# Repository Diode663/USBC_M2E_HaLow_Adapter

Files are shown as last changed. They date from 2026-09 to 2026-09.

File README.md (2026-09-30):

# USB-C to M.2 Key-E HaLow adapter

USB 2.0 over a USB-C receptacle to an M.2 2230 Key-E socket, for the Gateworks
GW16170 (Morse Micro MM8108-M20) Wi-Fi HaLow card. 56.5 x 40.5 mm, 2-layer
(JLCPCB JLC0216A), single-sided assembly.

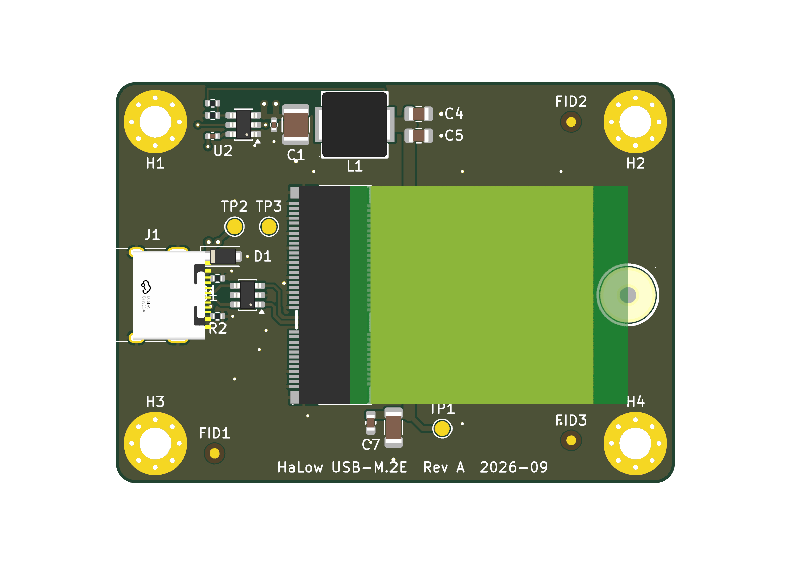
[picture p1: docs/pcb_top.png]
Top view with the card envelope


> **Status: Rev A is built and works as designed** (boards assembled by JLCPCB, confirmed by the
> author on 2026-09-29). The project is closed; no Rev B is planned.
> Test procedure: [`docs/Test_Procedure.md`](docs/Test_Procedure.md). Pre-fabrication review:
> [`docs/Design_Review_2026-09-20.md`](docs/Design_Review_2026-09-20.md).

| Block | Parts |
|---|---|
| USB-C input | J1 HRO TYPE-C-31-M-12, R1/R2 5.1k CC pull-downs, U1 USBLC6-2SC6, D1 SMF5.0A |
| 3.3 V / 3 A buck | U2 TPS563201, L1 2.2 uH, C1/C2 in, C4/C5 out, R3/R4 33.2k/10k = 3.32 V |
| M.2 socket | J2 MLD-NGFF-E-4.2H, C6 100 uF, C7 10 uF, C8/C9 100 nF |
| Mechanical | H1-H4 M3, H5 SMTSOM225BTR M2 x 2.5 mm SMT nut for the card |

Only USB D+/D- (M.2 pins 3 and 5), 3.3 V and ground go to the card. W_DISABLE1# (the card's
reset) and W_DISABLE2# (wake) are left open on purpose: the card has its own pull-ups, and its
reset pin uses a power-on RC that an external pull-up would defeat.

## Bill of materials

Full BOM with notes and the parts you supply yourself: **[`BOM.md`](BOM.md)**.
The CSV that went to JLCPCB: [`fab/USBC_M2E_HaLow_Adapter_bom.csv`](fab/USBC_M2E_HaLow_Adapter_bom.csv).

| Ref | Qty | Value | Part number | LCSC |
|---|---|---|---|---|
| U2 | 1 | 3 A buck regulator | TPS563201DDCR | C116592 |
| U1 | 1 | USB ESD array | USBLC6-2SC6 | C7519 |
| D1 | 1 | 5 V TVS | SMF5.0A | C19077497 |
| L1 | 1 | 2.2 µH | CYA0630-2.2UH | C5189746 |
| J1 | 1 | USB-C receptacle | TYPE-C-31-M-12 | C165948 |
| J2 | 1 | M.2 Key-E socket, 4.2 mm | MLD-NGFF-E-4.2H | C52766479 |
| H5 | 1 | M2 x 2.5 mm SMT nut | SMTSOM225BTR | C5301773 |
| C1 | 1 | 10 µF 25 V, 1210 | GRM32DR71E106KA12L | C77100 |
| C6 | 1 | 100 µF 6.3 V, 1206 | CL31A107MQHNNNE | C15008 |
| C4, C5 | 2 | 22 µF 25 V, 0805 | CL21A226MAQNNNE | C45783 |
| C7 | 1 | 10 µF 10 V, 0603 | CL10A106KP8NNNC | C19702 |
| C2, C3, C8, C9 | 4 | 100 nF 16 V, 0402 | CL05B104KO5NNNC | C1525 |
| R1, R2 | 2 | 5.1 kΩ 1 %, 0402 | 0402WGF5101TCE | C25905 |
| R3 | 1 | 33.2 kΩ 1 %, 0402 | FRC0402F3322TS | C2930001 |
| R4 | 1 | 10 kΩ 1 %, 0402 | 0402WGF1002TCE | C25744 |

You also need the GW16170 card, an M2 x 3–4 mm screw, an MMCX antenna or pigtail, and a short
3 A USB-C cable on a port that can supply about 0.9 A.

## How it was made

Everything is generated from Python. Edit the scripts, not the KiCad files. Run with KiCad's Python:

    "C:\Program Files\KiCad\10.0\bin\python.exe" generate_schematic.py --force
    "C:\Program Files\KiCad\10.0\bin\python.exe" autoplace.py . --floorplan
    "C:\Program Files\KiCad\10.0\bin\python.exe" autoplace.py . --place --force
    "C:\Program Files\KiCad\10.0\bin\python.exe" setup_fab.py
    "C:\Program Files\KiCad\10.0\bin\python.exe" route_board.py
    "C:\Program Files\KiCad\10.0\bin\python.exe" drc_report.py
    "C:\Program Files\KiCad\10.0\bin\python.exe" check_m2_clearance.py
    "C:\Program Files\KiCad\10.0\bin\python.exe" build_package.py

`--place` resets every unlocked footprint. Designators moved by hand in KiCad are detected and
kept (`.pcbgen-refs.json`). `route_board.py` redraws every track, via and pour each time it runs.
`build_package.py` writes `fab/` and refuses to run unless DRC is clean.

Mechanical facts, from the MLD-NGFF-E-4.2H drawing:
- the card extends from the even-pin / locating-peg side of the socket;
- the card stop is 1.75 mm behind the pegs, so the 2230 notch is 29.75 mm from the socket centre;
- the card's underside is 2.52 mm above the board; parts under it must be 0.90 mm or lower.

JLCPCB: `setup_fab.py` writes their 2-layer rules into the project and into
`USBC_M2E_HaLow_Adapter.kicad_dru`, with the source pages and date in its docstring. The USB pair
is 0.3345 / 0.1524 mm with ground pour 0.2032 mm either side, from JLCPCB's own calculator for
stackup JLC0216A. JLCPCB does not test impedance on 2-layer boards. `jlc_rotations.json` holds
the placement-file corrections with the evidence for each.

## Repository contents
- `USBC_M2E_HaLow_Adapter.kicad_*`: the KiCad 10 project, schematic, routed board and custom design rules.
- `fab/`: the package sent to JLCPCB for Rev A (gerbers zip, BOM, placement file, order notes).
- `docs/`: schematic PDF, renders, copper images, the pre-fabrication design review and the board test procedure.
- `library/`: project symbols, footprints and 3D models.
- `*.py`: the generators. `schlib.py`, `subcircuits.py`, `pcblib.py`, `autoplace.py`, `recipes.py` and `jlc_cpl.py` are copies of the libraries the project was generated with.
- Vendor datasheets are not included.

## Licence

Copyright Diode663 2026.

**Hardware** (the KiCad project, schematic, board, the project's own symbols and footprints,
fabrication outputs and documentation): this source describes Open Hardware and is licensed under
the CERN-OHL-P v2. You may redistribute and modify this source and make products using it under
the terms of the CERN-OHL-P v2 (<https://ohwr.org/cern_ohl_p_v2.txt>), a copy of which is in
[`LICENSE`](LICENSE). This source is distributed WITHOUT ANY EXPRESS OR IMPLIED WARRANTY,
INCLUDING OF MERCHANTABILITY, SATISFACTORY QUALITY AND FITNESS FOR A PARTICULAR PURPOSE. Please
see the CERN-OHL-P v2 for applicable conditions.
Source location: <https://github.com/Diode663/USBC_M2E_HaLow_Adapter>

**Software** (every `*.py` file): MIT, see [`LICENSE-MIT`](LICENSE-MIT).

**Not covered by either licence** — third-party material, included for convenience and owned by
its respective rights holders:
- footprints and 3D models obtained from LCSC / EasyEDA with `easyeda2kicad`:
  `library/HaLowAdapter.pretty/CONN-SMD_MLD-NGFF-E-4.2H.kicad_mod`, `IND-SMD_L7.2-W6.6_GPSR07X0.kicad_mod`,
  `SMTSO_M2_H2.5_SMTSOM225BTR.kicad_mod`, and in `library/HaLowAdapter.3dshapes/` the
  `USB-C_SMD-TYPE-C-31-M-12_1`, `IND-SMD_L7.2-W6.6-H3.0_GPSR07X0` and `SMD_BD5.6-D3.6` models;
- `USB_C_Receptacle_HRO_TYPE-C-31-M-12.kicad_mod` and the M.2 socket symbol, which are modified
  copies from the KiCad libraries (CC-BY-SA 4.0 with the KiCad library exception).

Gateworks, Morse Micro, JLCPCB and the part manufacturers are not affiliated with this project.

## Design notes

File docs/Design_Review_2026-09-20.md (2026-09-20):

# USB-C to M.2 Key-E HaLow Adapter — Design Review

**Project:** USBC_M2E_HaLow_Adapter (KiCad 10, single sheet, 2-layer PCB 56.5 x 40.5 mm, JLCPCB turnkey)
**Date:** 2026-09-20
**Analyzers run:** analyze_schematic.py, analyze_pcb.py `--full --proximity`, cross_analysis.py, analyze_emc.py, analyze_thermal.py, lifecycle_audit.py (LCSC only), KiCad DRC with schematic parity, project `check_m2_clearance.py`, deep review pass with the citation gate.
**Run folder:** `analysis/2026-09-20_1330/`, deep review in `analysis/deep_review.json`, numbers from `analysis/helpers/buck_usb_checks.py`.

## Overview
USB 2.0 over a USB-C receptacle (J1) to an M.2 2230 Key-E socket (J2) for a Gateworks GW16170 HaLow card. A TPS563201 buck (U2) makes 3.3 V from VBUS. ESD array U1 on D+/D-, TVS D1 on VBUS, 5.1k sink resistors on CC1/CC2. 24 parts, 10 routed nets, everything on the top side, solid ground pour on both layers.

No prior review or analyzer runs existed, so there is no delta section.

## Critical Findings

| Severity | Issue | Section |
|---|---|---|
| WARNING | +3V3 output capacitance (154 uF nominal, ~87 uF effective) is above TI's 20-68 uF range with L1 at its 4.7 uH maximum. LC pole 5.9-7.9 kHz vs TI's 8.9-24 kHz envelope. | Power |
| WARNING | A ground stitching via sits inside J2's hold-down tab pad 76. Solder will wick down it and weaken a mechanical joint. | Layout |
| WARNING | The ground via under U1 is 0.5/0.3 mm: 0.10 mm annular ring, below IPC Class 2 (0.125 mm). JLCPCB can build it; a 0.6/0.3 via fits. | Layout |

No CRITICAL issues. Nothing found that would stop the board from working.

## Component Summary
Capacitors 9, resistors 4, inductor 1, TVS 1, ICs 2, connectors 2, mounting parts 5. 63 nets (53 are single-pin no-connect nets on J2), 3 rails. MPN coverage 100 % of BOM parts. Two BOM lines have no manufacturer recorded: D1 (C19077497) and H5 (C5301773).

## Power Tree
```
USB-C VBUS 5 V --D1 SMF5.0A clamp-- C1 10uF + C2 100nF
   |
   U2 TPS563201 buck, 580 kHz, EN tied to VIN
   |   R3 33.2k / R4 10k -> 0.768 x 4.32 = 3.318 V   (Vref from datasheet)
   |   L1 4.7 uH, C4 + C5 22 uF at the inductor
   +3V3 --> J2 pins 2/4/72/74, C6 100 uF + C7 10 uF + C8/C9 100 nF at the socket
```
Load: GW16170, about 1.2 A at 3.3 V in transmit bursts (estimate; Gateworks publishes no figure), about 0.9 A from VBUS.

## Analyzer Verification (raw file and datasheet)
- Component count: 24 in schematic, 24 footprints on the board. DRC schematic parity 0. **Raw-file verified.**
- U2 pad nets 1 GND, 2 SW, 3 VBUS, 4 FB, 5 VBUS, 6 VBST match TI's pin table (p.3). **Datasheet-verified.**
- U1 pad nets 1/6 D-, 3/4 D+, 2 GND, 5 open match ST Figure 1. **Datasheet-verified.**
- J2 pad numbering, odd/even row positions, locating pegs and card direction match the MLD drawing; USB on pins 3/5 and 3.3 V on 2/4/72/74 match Gateworks' wiki. **Datasheet-verified.**
- D1 cathode (pad 1) on VBUS. **Raw-file verified**; no datasheet for this exact LCSC part.
- J1: KiCad's stock footprint and symbol for this exact MPN, LCSC C165948 as ordered before. **Library-consistent, not re-derived from the HRO datasheet.**
- Regulator Vout: analyzer 3.283 V (heuristic Vref), hand calculation with TI's 0.768 V: 3.318 V. Use 3.32 V.

## Deep Review
Seven findings passed the citation gate (all marked partial because no structured datasheet extractions exist; quotes are from the PDFs). One was quarantined for lack of a datasheet (D1) and is reported below as inference only.

## Signal Analysis — USB 2.0
- Coupled section uses JLCPCB's calculated geometry (0.3345 / 0.1524 mm, ground 0.2032 mm either side) over unbroken bottom ground. JLCPCB does not test impedance on 2-layer boards.
- From J1 through U1 (about 9 mm) D+ and D- run uncoupled, 1.9 mm apart at U1, because the part is flow-through. That section is well above 90 ohm differential. At 9 mm (about 60 ps) against a 500 ps USB 2.0 edge this is acceptable. **Inference-only.**
- Skew about 3 mm, 20 ps, against a 100 ps budget. Each line has one 1.3 mm bottom strap plus two vias as a side branch for the flip pads, not in the main path.
- No series resistors or common-mode choke. Fine for a bus-powered adapter; a choke is the usual fix if radiated emissions from the cable ever matter.

## Power Analysis
- **Output capacitance vs TI Table 2 (WARNING).** TI: "use the values recommended in Table 2": 3.3 V, L 2.2 typ / 4.7 max uH, Cout 20 to 68 uF. The socket's 100 uF sits on the same node through 11 mOhm of trace, so it counts. Effective capacitance uses typical X5R bias curves, not the capacitor datasheets. **Datasheet-verified limit, inference on the effective value.** Fix: L1 to 2.2 uH (same CYA0630 footprint; pole moves to 8.6-11.5 kHz, ripple 0.87 A pk-pk, peak 1.64 A, still far below the 3.3 A valley limit) and optionally C6 to 47 uF.
- **VBUS headroom (INFO).** TI's 75 % duty limit means VIN of at least 4.43 V for 3.3 V out; UVLO wake-up is 4.3 V max. Only 10 uF is allowed on VBUS. A long or thin cable can sag below that during transmit. Measure VBUS at C1 on the first board.
- C1 + C2 = 10.1 uF nominal on VBUS, at the USB limit of 10 uF; effective value under 5 V bias is lower. Acceptable.
- Current paths: VBUS trunk 0.8 mm bottom, +3V3 1.2 mm top, SW 1.2 mm bottom with two vias at each end. One 0.8/0.4 via carries all VBUS current at D1 (0.9 A): within rating, a second via is cheap.
- M.2 3.3 V pins: four at 0.5 A each, 2 A capacity for a 1.2 A load.

## PCB Layout
- DRC: 0 errors, 0 unconnected, parity 0. 51 silkscreen warnings, 49 of them inside stock KiCad footprints (silk 0.10-0.13 mm from their own pads; JLCPCB clips silk at pads).
- M.2 mechanical check: all clear. L1 2.90 mm from the socket housing, 0402s under the card 0.50 mm tall against a 0.90 mm limit, standoff on the notch at 2.50 mm.
- **Via in J2 pad 76 (WARNING):** stitching via at (19.4, 32.4) lands in the hold-down tab. Move it 1 mm south.
- **Under-U1 via ring (WARNING):** change to 0.6/0.3; clearance to U1's pads becomes 0.18 mm against a 0.15 mm rule.
- Buck follows TI Figure 36 with one known deviation (output caps return through pour and plane, not a shared top island). Solid pour connections on all buck ground pads.
- Tombstoning: analyzer rates six 0402s "medium". C2's ground pad is solid into the pour by choice (input loop); the rest have thermal spokes. Accepted.

## Thermal
analyze_thermal.py produced no assessments (no dissipation data in the schematic). Hand estimate: 0.38 W in U2 at 1.2 A, 92.6 C/W, about 35 C rise. Efficiency is assumed at 90 %, not read from TI's curves. No concern. The radio card's own heat is outside this board.

## EMC / Cross-Domain
- SW-001 harmonics of 580 kHz in the 30-88 MHz band: generic to any buck. SW is 24 mm of copper, 18 mm of it on the bottom under the buck. Inductor is shielded (metal composite).
- The HaLow radio listens at 902-928 MHz, 25 mm from the buck. Harmonic energy that high is small, but the receiver is sensitive. **Inference-only:** check receive sensitivity with the buck loaded on the first board.

## Component Lifecycle
LCSC returns no lifecycle status, so all 14 MPNs read "unknown". No distributor API keys are configured. **Not verified.** TPS563201, USBLC6-2SC6 and the Samsung/Murata capacitors are mainstream active parts to my knowledge.

## Manufacturing / DFM / Testability
- JLCPCB Economic PCBA limits met (2-layer, single side, 0402 minimum, 0.5 mm pitch). Not confirmed: whether J1 (overhangs the edge 0.5 mm) and J2 are allowed in Economic assembly.
- No fiducials (analyzer FD-001 "error"). JLCPCB Economic does not require them. Three 1 mm fiducials cost nothing and help with the 0.5 mm pitch socket. **Suggestion.**
- No test points. Suggest pads on +3V3, VBUS and GND, and optionally J2 pin 56 (card reset).
- Silkscreen has no board name, revision or date.
- CPL: five rotations unverified (D1, J1, J2, U1, U2). Check in JLCPCB's preview.
- BOM: add manufacturers for D1 and H5.

## False Positives / Reviewer Overrides
- UC-002 "no TVS on VBUS": D1 is the VBUS TVS; the analyzer does not recognise the Zener symbol.
- EMC DC-002 "no decoupling near U1": U1 is a passive ESD array with its supply pin open by design.
- EMC EF-001 / LC-DET "EMI filter at 232 kHz": that is L1 with the bootstrap capacitor, not a filter.
- EMC RP-001 "missing stitching via at layer transition" on USB: the transitions are the 1.3 mm flip-pad branches, not the signal path. Downgraded to info.
- RP-002 / PS-002 "SW crosses VBUS plane gap, VBUS split into 5 islands": VBUS is routed as tracks, not a plane.
- VP-001 says "untented": board setup tents vias on both sides. The via-in-pad part of the finding is real.
- CC-DET "+3V3 0.2 mm min trace": that is the feedback sense line, which carries no load current.
- Pin 56/54 pull-ups: reviewed separately; must stay open (Morse Micro reset RC).

## Not Performed / Review Limits
- SPICE: no simulator installed (ngspice, LTspice, Xyce all absent).
- Gerber analysis: no fabrication outputs exist yet.
- Lifecycle: no usable data (see above).
- Structured datasheet extraction: none; PDFs read directly. No datasheets on hand for D1, H5, the 0402/0603 capacitors or the 5.1k resistors.
- GW16170 current draw is an estimate; Gateworks publishes none.
- Capacitor DC-bias figures are typical-curve estimates.

## Verdict
**Ready for fabrication after three small fixes:** move the via out of J2 pad 76, enlarge the under-U1 via to 0.6/0.3, and change L1 to 2.2 uH (or accept the stability risk knowingly and check load-step response). Everything else is optional polish: second VBUS via, fiducials, test points, silkscreen ID, BOM manufacturers.

## Post-Review Changes (2026-09-20, same day)
All three warnings and the optional items were applied, then every check was re-run.

| Item | Change | Result |
|---|---|---|
| Output filter | L1 4.7 uH -> 2.2 uH, CYA0630-2.2UH, LCSC C5189746 (7 A / 10 A, 15.5 mOhm), same footprint | LC pole 8.6-11.5 kHz; effective Cout (~87 uF est.) is still above TI's 68 uF. Ripple 0.87 A pk-pk, 1.64 A peak. |
| Via in J2 pad 76 | stitching via moved 1.3 mm south, clear of the hold-down tab | analyzer VP-001 gone |
| Under-U1 ground via | 0.5/0.3 -> 0.6/0.3 mm | DFM-001 / DFM-002 gone |
| VBUS at D1 | second 0.8/0.4 via | two vias share 0.9 A |
| Fiducials | FID1-FID3, 1 mm, asymmetric triangle | FD-001 gone |
| Test pads | TP1 +3V3, TP2 VBUS, TP3 GND, 1.5 mm, outside the card outline | reachable with the card fitted |
| Silkscreen | "HaLow USB-M.2E  Rev A  2026-09" | 1.0 mm / 0.15 mm, JLCPCB legend minimum |
| BOM | D1 manufacturer R+O, H5 manufacturer YIYUAN | complete |

Re-check: KiCad DRC 0 errors / 0 unconnected / parity 0; M.2 clearance all clear; schematic netlist
matches the spec, ERC 0; PCB analyzer has no errors and one warning left (test-point coverage metric);
gerber analysis of `fab/gerbers/`: 9 layers + 2 drill files, complete, aligned, 56.5 x 40.5 mm, no findings.
Still open and not fixable on paper: JLCPCB Economic vs Standard assembly for J1/J2, five CPL
rotations to confirm in JLCPCB's preview, and the bring-up measurements listed in `fab/ORDER_NOTES.txt`.

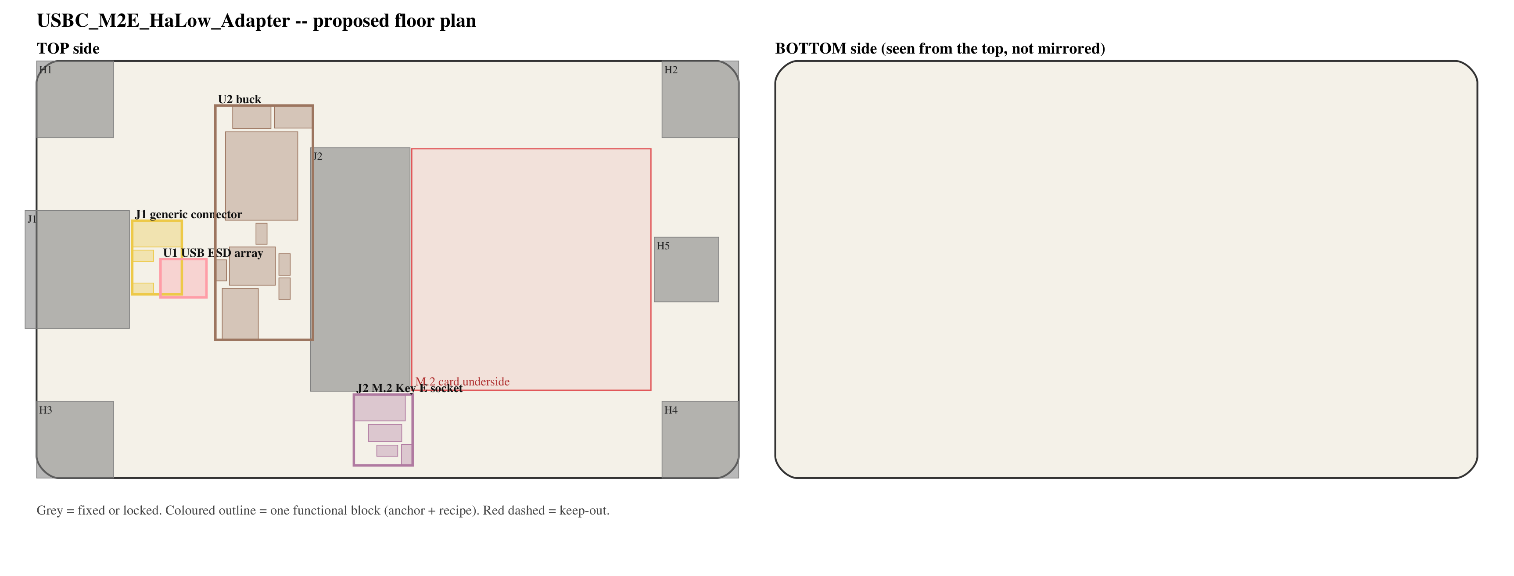
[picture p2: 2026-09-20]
docs/floorplan.png

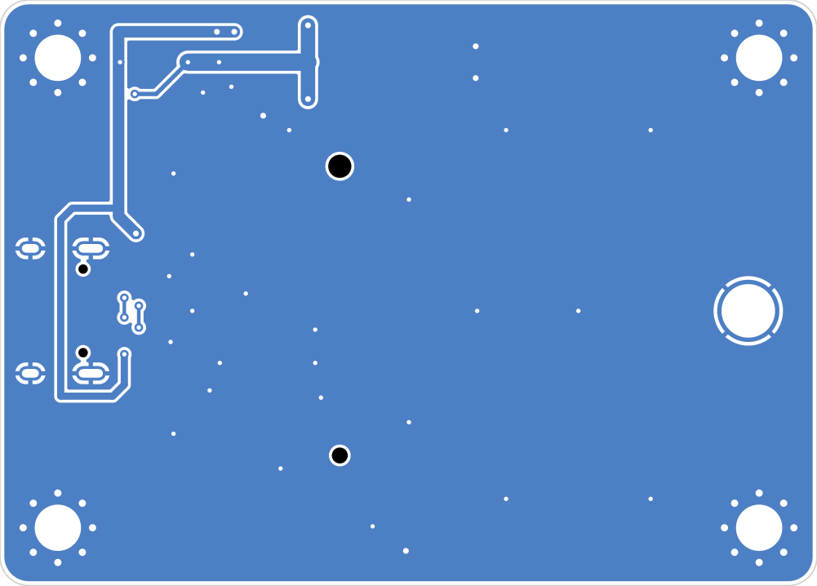
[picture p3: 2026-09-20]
docs/copper_B.png

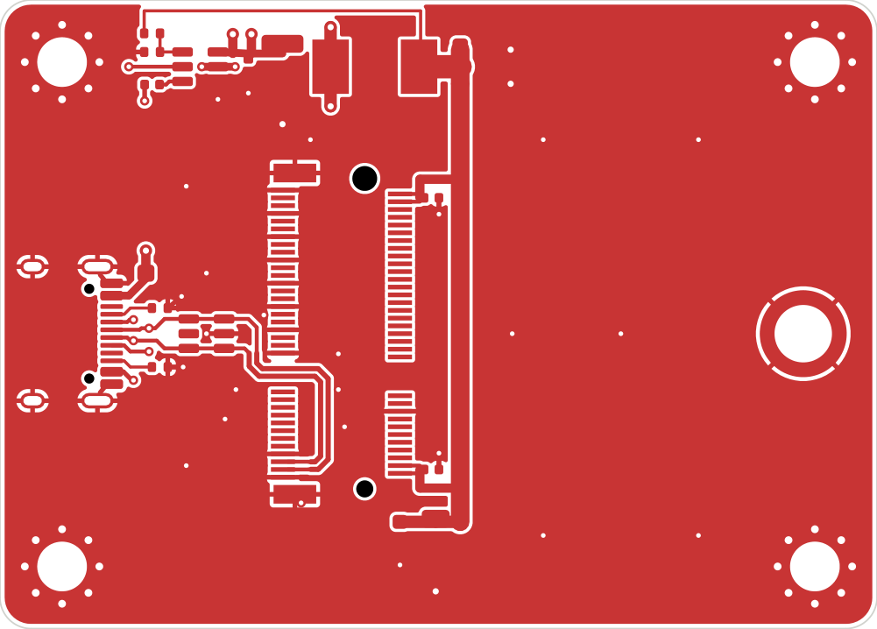
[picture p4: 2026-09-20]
docs/copper_F.png

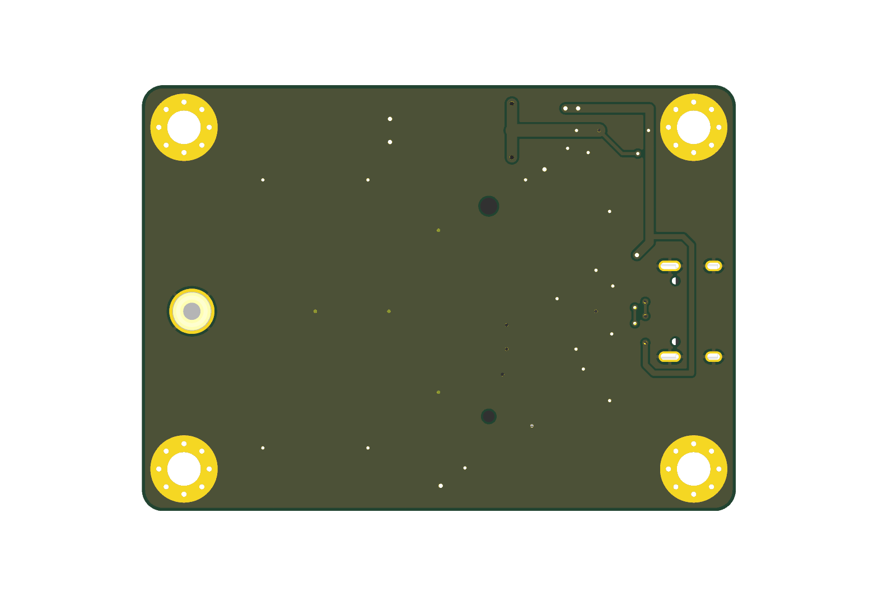
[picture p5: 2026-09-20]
docs/pcb_bottom.png

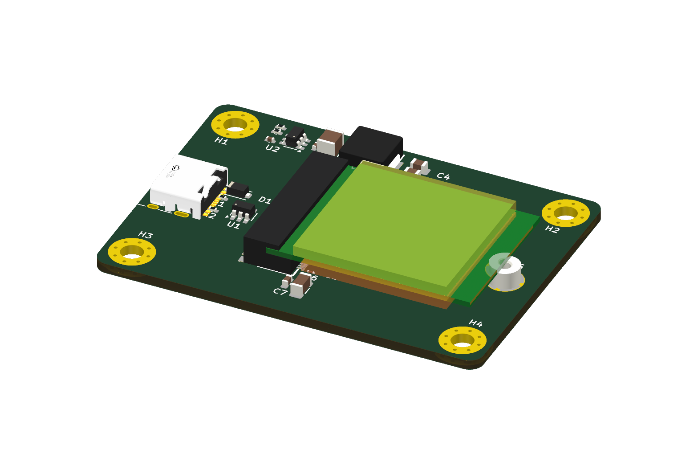
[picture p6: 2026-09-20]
docs/pcb_angled.png

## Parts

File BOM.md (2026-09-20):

# Bill of materials — Rev A

Machine-readable copy, exactly as uploaded to JLCPCB: [`fab/USBC_M2E_HaLow_Adapter_bom.csv`](fab/USBC_M2E_HaLow_Adapter_bom.csv).
Placement file: [`fab/USBC_M2E_HaLow_Adapter_cpl.csv`](fab/USBC_M2E_HaLow_Adapter_cpl.csv).

## Assembled by JLCPCB (15 lines, 20 parts, all top side)

| Ref | Qty | Value | Part number | Manufacturer | Package | LCSC |
|---|---|---|---|---|---|---|
| U2 | 1 | 3 A synchronous buck, 3.3 V rail | TPS563201DDCR | Texas Instruments | SOT-23-6 | C116592 |
| U1 | 1 | USB 2.0 ESD array | USBLC6-2SC6 | STMicroelectronics | SOT-23-6 | C7519 |
| D1 | 1 | 5 V TVS on VBUS | SMF5.0A | R+O | SOD-123FL | C19077497 |
| L1 | 1 | 2.2 µH, 7 A / 10 A sat, 15.5 mΩ | CYA0630-2.2UH | SHOU HAN | 7.2 x 6.6 x 3.0 mm | C5189746 |
| J1 | 1 | USB-C receptacle, USB 2.0, 16 pin | TYPE-C-31-M-12 | HRO (Korean Hroparts) | SMD, right angle | C165948 |
| J2 | 1 | M.2 Key-E socket, 4.2 mm high | MLD-NGFF-E-4.2H | MLD (Minlenda) | SMD, 67 pin | C52766479 |
| H5 | 1 | M2 x 2.5 mm SMT nut, card standoff | SMTSOM225BTR | YIYUAN | 5.6 mm body, 3.7 mm hole | C5301773 |
| C1 | 1 | 10 µF 25 V X7R | GRM32DR71E106KA12L | Murata | 1210 | C77100 |
| C6 | 1 | 100 µF 6.3 V X5R | CL31A107MQHNNNE | Samsung Electro-Mechanics | 1206 | C15008 |
| C4, C5 | 2 | 22 µF 25 V X5R | CL21A226MAQNNNE | Samsung Electro-Mechanics | 0805 | C45783 |
| C7 | 1 | 10 µF 10 V X5R | CL10A106KP8NNNC | Samsung Electro-Mechanics | 0603 | C19702 |
| C2, C3, C8, C9 | 4 | 100 nF 16 V X7R | CL05B104KO5NNNC | Samsung Electro-Mechanics | 0402 | C1525 |
| R1, R2 | 2 | 5.1 kΩ 1 % | 0402WGF5101TCE | Uniroyal | 0402 | C25905 |
| R3 | 1 | 33.2 kΩ 1 % | FRC0402F3322TS | Uniroyal | 0402 | C2930001 |
| R4 | 1 | 10 kΩ 1 % | 0402WGF1002TCE | Uniroyal | 0402 | C25744 |

Notes
- J1, J2 and H5 are listed by JLCPCB as "SMT Assembly, PCBA Type: Economic and Standard" (checked 2026-09-20). All three, and most of the ICs, are Extended-library parts.
- The CSV sent to JLCPCB names the Samsung capacitors' manufacturer as "CCTC". JLCPCB matches on the LCSC number, so the order is unaffected; the table above has the correct maker.
- L1 is 2.2 µH on purpose: TI's table for the TPS563201 gives 2.2 µH typical at 3.3 V, and with the socket's bulk capacitor on the same rail it keeps the output filter inside TI's range. See `docs/Design_Review_2026-09-20.md`.

## On the board but not populated

| Ref | What | Footprint |
|---|---|---|
| H1–H4 | M3 mounting holes, plated and grounded | 3.2 mm hole, 6.4 mm pad |
| FID1–FID3 | 1 mm fiducials | — |
| TP1, TP2, TP3 | 1.5 mm test pads: +3V3, VBUS, GND | — |

## You supply

| Qty | Item | Notes |
|---|---|---|
| 1 | Gateworks GW16170 Wi-Fi HaLow card | M.2 2230 Key-E, USB 2.0 on pins 3/5, 3.3 V only. The GW16167 has the same pinout. The GW16159 is SDIO-only and will not work. |
| 1 | M2 x 3 mm or 4 mm pan-head screw | Holds the card to H5. |
| 1 | MMCX antenna or MMCX pigtail | The antenna connector is on the card, not on this board. 902–928 MHz. |
| 1 | USB-C cable rated 3 A, short | The card can pull about 0.9 A from VBUS in transmit bursts (estimate). Use a USB 3 / USB-C host port or a powered hub, not a 500 mA USB 2.0 port. |
| 4 | M3 screws and standoffs | Optional, for mounting. |

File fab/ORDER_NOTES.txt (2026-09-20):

JLCPCB order settings for USBC_M2E_HaLow_Adapter (Rev A)

PCB
  Layers 2, 56.5 x 40.5 mm, thickness 1.6 mm, outer copper 1 oz, FR-4.
  Surface finish: LeadFree HASL is fine; ENIG is nicer for the 0.5 mm pitch M.2 socket.
  Via covering: tented. Min via hole 0.3 mm / diameter 0.6 mm (no surcharge tier).
  Impedance control: NO. JLCPCB does not offer it on 2 layers. The USB pair is drawn
  to their calculator's numbers for stackup JLC0216A: 0.3345 / 0.1524 mm, ground 0.2032 mm.
  Remove order number: optional ("Specify a location" is not drawn on this board).

PCB assembly
  Side: top only. Economic PCBA. JLCPCB's parts library lists J1 (C165948), J2 (C52766479)
  and H5 (C5301773) as "SMT Assembly, PCBA Type: Economic and Standard" (checked 2026-09-20).
  All three are Extended parts. J1 overhangs the board edge by 0.5 mm: if their engineer
  queries that at file review, it is intentional.
  Tooling holes: added by JLCPCB. Fiducials FID1-FID3 are on the board.
  Files: *_bom.csv and *_cpl.csv from this folder.
  Not populated by design: H1-H4 (holes), FID1-3, TP1-3. They have no LCSC number and
  are in neither file.
  Placement corrections are in jlc_rotations.json, each with its evidence. JLCPCB's zero
  orientation belongs to THEIR footprint for each LCSC part: U1 (C7519) needs +270, U2
  (C116592) needs +180 although both are SOT-23-6, and J1's origin is 1.57 mm nearer its pads.
  LOOK AT THESE AGAIN in the placement preview after uploading this CPL:
    U1  pin 1 dot bottom-right, on the silkscreen triangle   (was wrong, now corrected)
    U2  pin 1 dot bottom-right, on the silkscreen triangle   (corrected from their footprint, not yet seen)
    J1  contacts sitting on the pads, opening toward the left edge   (shifted 1.57 mm)
    D1  cathode band on the J1 side;  J2 slot opening toward H5
  H5 is an M2 x 2.5 mm SMT nut (C5301773) that seats in a 3.7 mm plated hole.

First board bring-up
  Measure VBUS at C1 during transmit (TI wants >= 4.43 V for 3.3 V out).
  Check 3.3 V load-step / ripple at TP1, and receive sensitivity with the buck loaded.

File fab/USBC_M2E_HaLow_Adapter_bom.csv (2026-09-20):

Comment | Designator | Footprint | LCSC Part # | MPN | Manufacturer | Quantity
10uF/25V | C1 | C_1210_3225Metric | C77100 | GRM32DR71E106KA12L | Murata | 1
100nF | C2,C3,C8,C9 | C_0402_1005Metric | C1525 | CL05B104KO5NNNC | CCTC | 4
22uF | C4,C5 | C_0805_2012Metric | C45783 | CL21A226MAQNNNE | CCTC | 2
100uF | C6 | C_1206_3216Metric | C15008 | CL31A107MQHNNNE | Samsung | 1
10uF | C7 | C_0603_1608Metric | C19702 | CL10A106KP8NNNC | CCTC | 1
SMF5.0A | D1 | D_SOD-123F | C19077497 | SMF5.0A | R+O | 1
M2 standoff H2.5 | H5 | SMTSO_M2_H2.5_SMTSOM225BTR | C5301773 | SMTSOM225BTR | YIYUAN | 1
USB-C | J1 | USB_C_Receptacle_HRO_TYPE-C-31-M-12 | C165948 | TYPE-C-31-M-12 | HRO | 1
M.2 Key-E (GW16170) | J2 | CONN-SMD_MLD-NGFF-E-4.2H | C52766479 | MLD-NGFF-E-4.2H | MLD | 1
2.2uH | L1 | IND-SMD_L7.2-W6.6_GPSR07X0 | C5189746 | CYA0630-2.2UH | SHOU HAN | 1
5.1k | R1,R2 | R_0402_1005Metric | C25905 | 0402WGF5101TCE | Uniroyal | 2
33.2k | R3 | R_0402_1005Metric | C2930001 | FRC0402F3322TS | Uniroyal | 1
10k | R4 | R_0402_1005Metric | C25744 | 0402WGF1002TCE | Uniroyal | 1
USBLC6-2SC6 | U1 | SOT-23-6 | C7519 | USBLC6-2SC6 | STMicroelectronics | 1
TPS563201DDCR | U2 | SOT-23-6 | C116592 | TPS563201DDCR | Texas Instruments | 1

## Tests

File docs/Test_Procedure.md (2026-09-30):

# Board test procedure — Rev A

For the USB-C to M.2 Key-E HaLow adapter as sent to JLCPCB on 2026-09-20. Work through the
stages in order and stop at the first failure: each stage assumes the one before it passed.
Fill in the record sheet at the end for every board.

## Probe points

Coordinates are millimetres from the board's top-left corner (the origin the gerbers and
placement file use), X to the right, Y down. All test pads are on the top side.

| Point | Net | Where | What it is for |
|---|---|---|---|
| **TP2** | VBUS | 1.5 mm pad at (12.0, 14.6), above the USB-C, left of TP3 | USB input voltage as it arrives |
| **TP1** | +3V3 | 1.5 mm pad at (33.0, 35.0), below the socket's pin 2/4 end | regulator output, at the socket end of the rail |
| **TP3** | GND | 1.5 mm pad at (15.5, 14.6), right of TP2 | meter ground; scope ground spring for TP2 |
| H1–H4 | GND | the four M3 hole rings | scope ground clip; H2 is the closest ground to TP1 |
| C1 top pad | VBUS | 1210 capacitor at (18.2, 2.8), the pad nearer the board edge | VBUS at the regulator input: the drop across the board is TP2 minus this |
| L1 left pad | SW | inductor at (21.3, 4.3) | switch node, scope only |
| L1 right pad | +3V3 | inductor at (27.0, 4.3) | regulator output before the trace to the socket |
| U2 top-left pin | FB | pin 4 of the SOT-23-6 at (11.8, 3.4), or R4's right pad at (10.3, 3.4) | feedback reference, 0.768 V |
| J2 pins 2, 4, 72, 74 | +3V3 | socket pads, even row (the row under the card), both ends | rail at the card |

TP1 and TP2 sit outside the card outline, so they stay reachable with the card fitted.
The 0402 and SOT-23 pads are small: use a fine probe tip and steady your hand on the board.

## Equipment

- Bench supply with adjustable current limit, and a USB-C breakout board or a cut USB-C cable
  (VBUS and GND only). A USB power meter that shows volts and amps in-line is a good substitute
  for stages 3 and 5 if you have no breakout.
- Multimeter.
- Oscilloscope, at least 50 MHz, with a ground spring for the probe.
- Electronic load, or a 2.7 Ω, 10 W resistor with leads (a 5 W part gets hot at 4 W).
- A USB-A-to-C cable and a C-to-C cable, both 3 A rated, short.
- Host computer with a USB 3 or USB-C port (a 500 mA USB 2.0 port is not enough for the card).
- Gateworks GW16170 card with its MMCX antenna or pigtail, and an M2 screw.
- Hand magnifier or USB microscope for stage 1.

## Stage 1 — visual inspection, unpowered

The placement file carried corrections that were derived from JLCPCB's footprints and not all
seen in their viewer before ordering. Check these first; a turned part fails everything after.

| Part | Check |
|---|---|
| U1 (ESD, next to the USB-C) | pin-1 dot on the silkscreen triangle, bottom-right corner |
| U2 (regulator, top-left) | pin-1 dot on the silkscreen triangle, bottom-right corner |
| J1 (USB-C) | contacts sit centred on their pads; shell stakes soldered in all four holes |
| D1 (TVS above the USB-C) | cathode band on the side nearer J1 |
| J2 (M.2 socket) | slot opening toward H5 (the standoff), both hold-down tabs soldered |
| L1 | flat on its pads, no tilt |
| H5 | nut sits flush in its hole, fillet all round |
| C1 (the tall 1210 standing on end) | not tombstoned |
| all 0402s | both ends wetted |

Also confirm the hidden designators were not populated by mistake: nothing should sit at
FID1–FID3 or on TP1–TP3.

## Stage 2 — resistance checks, unpowered

Meter on ohms, black lead on TP3.

| Red lead on | Expect | Fail if |
|---|---|---|
| TP2 (VBUS) | rises toward several kΩ as capacitors charge; no short | under 100 Ω and steady |
| TP1 (+3V3) | rises toward tens of kΩ (R3 + R4 = 43 kΩ across the rail) | under 100 Ω and steady |
| J1 CC1 and CC2 pads (A5 and B5, the outer signal pads) | 5.1 kΩ each | open, or anything but ~5.1 kΩ |
| J2 pin 3 and pin 5 (USB D+, D−, odd row) | open, over 1 MΩ | short to ground |
| each M3 hole ring | 0 Ω | open |
| H5 | 0 Ω | open |

Diode test, red on TP3, black on TP2: D1 should read as a diode, about 0.6–0.7 V. Reversed
(red on TP2) it should read open, because at meter currents the 5 V TVS does not conduct.

## Stage 3 — first power, no card

1. Bench supply to 5.00 V, current limit 0.10 A, output off. Connect it to VBUS and GND
   through the breakout. Card not fitted.
2. Output on. Supply current must be **under 10 mA** (the regulator idles at about 0.4 mA and
   the feedback divider takes 0.08 mA). If the supply goes into current limit, power off:
   there is a short, most likely at U2 or L1.
3. Measure:

| Point | Expect | Note |
|---|---|---|
| TP2 | 4.95–5.05 V | equals the supply |
| TP1 | **3.25–3.39 V** (3.32 V nominal) | 0.768 V reference ±1 %, resistors ±1 % |
| U2 pin 4 (FB) | 0.76–0.78 V | if TP1 is wrong but FB is right, the divider is wrong |
| L1 right pad | same as TP1 within 5 mV | |

4. Scope, ground spring on TP3 or H2, 20 MHz bandwidth limit, AC coupled, 20 mV/div:
   ripple on TP1. With no load the regulator pulse-skips (TI's Eco-mode), so expect an irregular
   low-frequency pattern rather than a clean 580 kHz. Record the peak-to-peak; **under 50 mV**
   is the pass line.
5. Raise the current limit to 0.5 A and repeat step 2 briefly. Current should not change.

## Stage 4 — load test, no card

This stands in for the card's transmit bursts (about 1.2 A at 3.3 V) without risking the card.

1. Supply 5.00 V, current limit 1.5 A.
2. Load between TP1 and TP3: electronic load at 1.2 A constant current, or the 2.7 Ω resistor
   (1.23 A). Keep the leads short; the load's own voltage reading is not TP1.
3. Measure within a minute of applying the load:

| Point | Expect | Fail if |
|---|---|---|
| TP1 | 3.25–3.39 V, droop from stage 3 under 50 mV | below 3.20 V |
| supply current | 0.85–1.0 A | over 1.1 A |
| TP2 minus C1 top pad | under 50 mV | over 100 mV: VBUS trace or via problem |
| TP1 ripple, scope as before | under 50 mV pk-pk at ~580 kHz | |
| L1 left pad (SW), scope DC 2 V/div, ×10 probe | 0 to 5 V square wave at 580 kHz ±15 %, no ringing above about 7 V | ringing above 10 V, or frequency far off |
| U2 and L1 by touch after two minutes | warm, touchable | too hot to touch: about 60 °C is expected, 100 °C is not |

4. Step the load from 0 to 1.2 A and back while watching TP1 on the scope, DC coupled, 100
   mV/div: a dip or overshoot of under 150 mV that settles within about 100 µs with no
   oscillation. This is the check the design review asked for after the inductor change; it is
   the one stage-4 result worth keeping a screenshot of.
5. Remove the load.

## Stage 5 — cable and host checks, no card

1. Move from the bench supply to the host computer with the **A-to-C cable**. TP2 should show
   the host's VBUS, 4.75–5.25 V. Some hosts sit low; note the value.
2. Repeat with the **C-to-C cable**. VBUS must still appear: this proves the 5.1 kΩ CC
   resistors, because a C-to-C source gives no VBUS without them.
3. Flip the plug and check TP2 again with each cable.

## Stage 6 — card fitted, idle

1. Host off or cable out. Fit the GW16170: slide it into J2 at an angle, press down, fix with
   the M2 screw into H5. Fit the antenna before powering; a HaLow module transmitting into no
   antenna can be damaged.
2. Connect the host through the USB power meter, A-to-C cable.
3. Within ten seconds the host must see a new USB device (`dmesg`, `lsusb`, or Device Manager).
   If it does not, first measure J2 pins 56 and 54 (odd row, both near the pin 74 end): both
   must read 3.3 V. Gateworks' wiki names those two pins as the reason a card fails to
   enumerate. They are pulled up on the card and left open on this board, so anything but 3.3 V
   points at the socket.
4. Record the idle current from the power meter and TP1, TP2 with the card idle. Gateworks
   publishes no current figures; whatever you measure becomes the reference for later boards.

## Stage 7 — card transmitting

1. Bring the interface up and run traffic against a second HaLow node (iperf, or the driver's
   own test mode) at the power level you will use in service.
2. During transmit:

| Point | Expect | Fail if |
|---|---|---|
| TP2, meter min-hold or scope | **at least 4.50 V** | below 4.45 V: the regulator needs 4.43 V in for 3.3 V out and its undervoltage lockout is at 4.3 V; try a shorter cable or a stronger port before blaming the board |
| TP1 | above 3.20 V throughout | |
| TP1 on the scope, DC, 100 mV/div, slow timebase | bursts visible as small dips, under 150 mV | rail collapsing during bursts |
| power meter | note the peak; about 0.9 A is the design estimate | |

3. Receive check: compare received signal strength or throughput from the far node with this
   board against a known-good host for the same card and antenna. The regulator is 25 mm from
   the radio; a noticeably worse receive figure here would mean its harmonics are getting in.
4. After ten minutes of traffic, U2 and L1 by touch: warm, not hot.

## Record sheet

Board serial: ______   Date: ______   Tester: ______   Host / cable: ______

| Stage | Measurement | Limit | Value | Pass |
|---|---|---|---|---|
| 1 | U1, U2, J1, D1, J2 orientation | as listed | | |
| 2 | VBUS to GND, +3V3 to GND | not shorted | | |
| 2 | CC1, CC2 to GND | 5.1 kΩ | | |
| 3 | idle current, no card | < 10 mA | | |
| 3 | TP2 | 4.95–5.05 V | | |
| 3 | TP1 | 3.25–3.39 V | | |
| 3 | FB | 0.76–0.78 V | | |
| 3 | TP1 ripple, no load | < 50 mV pp | | |
| 4 | TP1 at 1.2 A | > 3.20 V, droop < 50 mV | | |
| 4 | supply current at 1.2 A | < 1.1 A | | |
| 4 | TP2 − C1 at 1.2 A | < 100 mV | | |
| 4 | SW frequency | 580 kHz ±15 % | | |
| 4 | load step on TP1 | < 150 mV, no oscillation | | |
| 5 | VBUS with C-to-C cable | present | | |
| 6 | card enumerates | yes | | |
| 6 | idle current with card | record | | |
| 7 | TP2 minimum during transmit | ≥ 4.50 V | | |
| 7 | TP1 minimum during transmit | ≥ 3.20 V | | |
| 7 | peak current during transmit | record | | |
| 7 | receive figure vs reference host | comparable | | |

Rev A result: the first boards worked as designed (2026-09-29). The README status and the
placement corrections in `jlc_rotations.json` were updated to say so.

## Where the limits come from

- 3.32 V nominal and the FB voltage: TI TPS563201 datasheet, 0.768 V reference, R3/R4 33.2k/10k.
- 4.43 V minimum input and 4.3 V undervoltage lockout: TI, section 9 and the electrical table.
- 580 kHz and the pulse-skipping at light load: TI, sections 7.4.1 and 7.4.2.
- About 0.9 A from VBUS and 1.2 A at 3.3 V: estimate for the GW16170 at full power; Gateworks
  publishes none, which is why stages 6 and 7 record rather than judge those numbers.
- Enumeration and pins 54/56: Gateworks GW16167/GW16170 wiki.
- Ripple, droop and load-step limits are engineering judgement for a rail feeding a radio, not
  datasheet figures.

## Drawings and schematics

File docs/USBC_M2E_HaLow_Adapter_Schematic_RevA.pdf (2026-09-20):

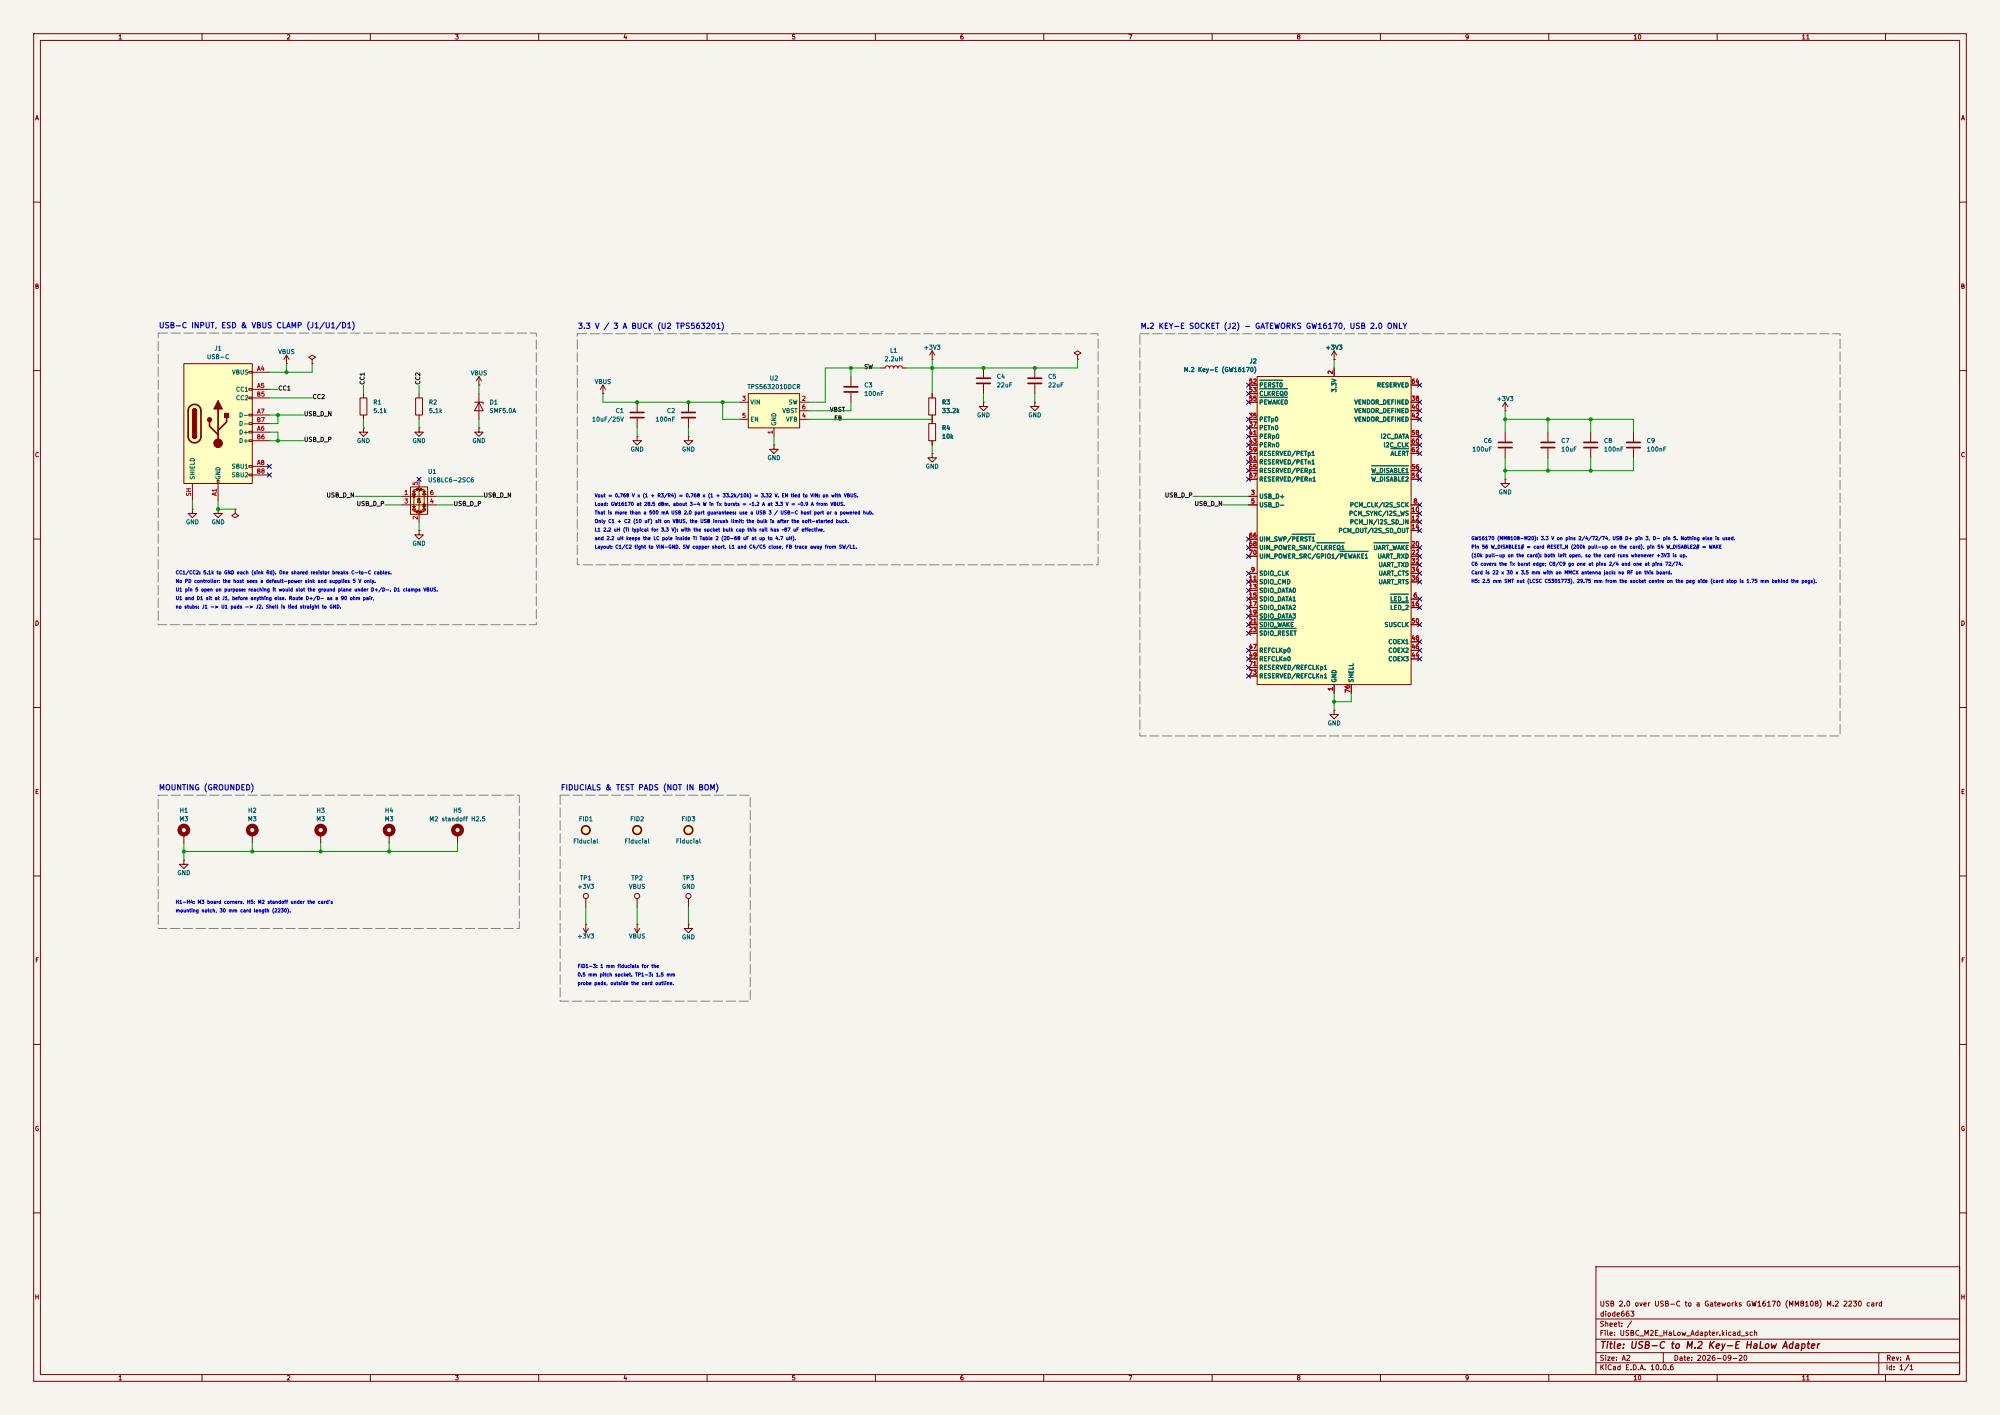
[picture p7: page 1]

(10k pull-up on the card): both left open, so the card runs whenever +3V3 is up. 3.3 V / 3 A BUCK (U2 TPS563201)

That is more than a 500 mA USB 2.0 port guarantees: use a USB 3 / USB-C host port or a powered hub. MOUNTING (GROUNDED)

Pin 56 W_DISABLE1# = card RESET_N (200k pull-up on the card), pin 54 W_DISABLE2# = WAKE C6 covers the Tx burst edge; C8/C9 go one at pins 2/4 and one at pins 72/74. H5: 2.5 mm SMT nut (LCSC C5301773), 29.75 mm from the socket centre on the peg side (card stop is 1.75 mm behind the pegs). GW16170 (MM8108-M20): 3.3 V on pins 2/4/72/74, USB D+ pin 3, D- pin 5. Nothing else is used. FIDUCIALS & TEST PADS (NOT IN BOM)

Card is 22 x 30 x 3.5 mm with an MMCX antenna jack: no RF on this board. and 2.2 uH keeps the LC pole inside TI Table 2 (20-68 uF at up to 4.7 uH).

CC1/CC2: 5.1k to GND each (sink Rd). One shared resistor breaks C-to-C cables.
U1 and D1 sit at J1, before anything else. Route D+/D- as a 90 ohm pair, No PD controller: the host sees a default-power sink and supplies 5 V only. no stubs: J1 -> U1 pads -> J2. Shell is tied straight to GND. mounting notch, 30 mm card length (2230). H1-H4: M3 board corners. H5: M2 standoff under the card's

FID1-3: 1 mm fiducials for the probe pads, outside the card outline. 0.5 mm pitch socket. TP1-3: 1.5 mm

USB 2.0 over USB-C to a Gateworks GW16170 (MM8108) M.2 2230 card
diode663
Sheet: /
File: USBC_M2E_HaLow_Adapter.kicad_sch
Title: USB-C to M.2 Key-E HaLow Adapter

Size: A2 | Rev: A
KiCad E.D.A. 10.0.6 | Id: 1/1

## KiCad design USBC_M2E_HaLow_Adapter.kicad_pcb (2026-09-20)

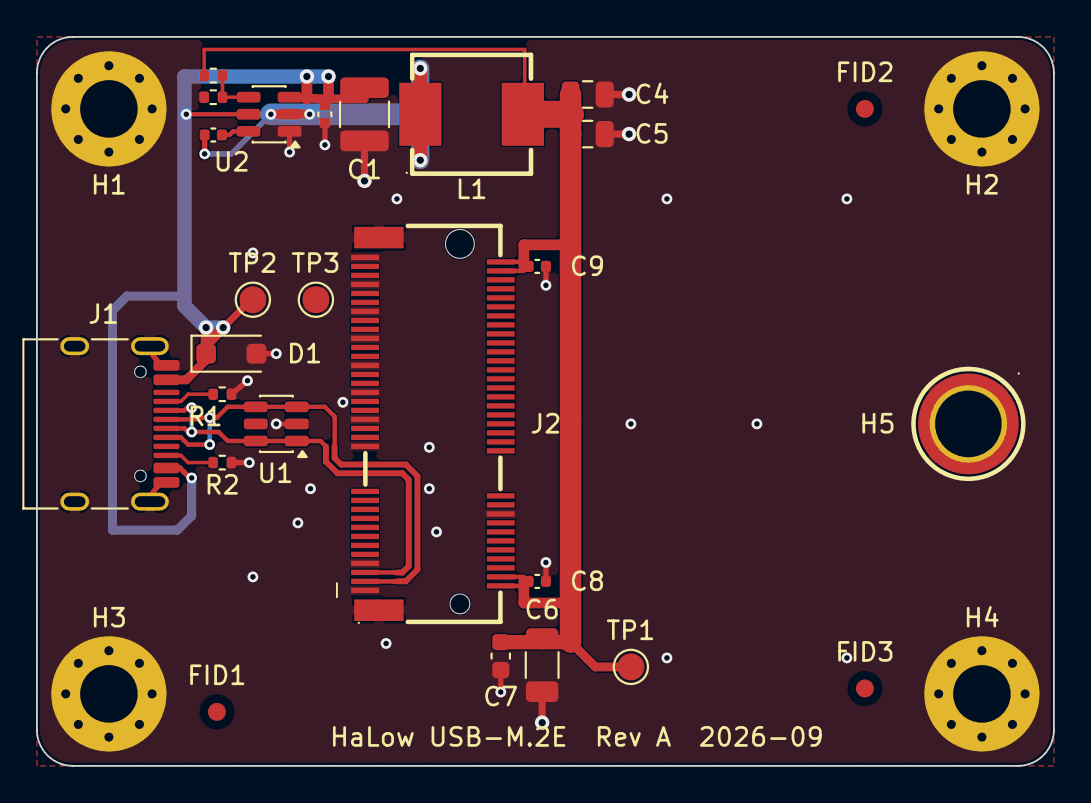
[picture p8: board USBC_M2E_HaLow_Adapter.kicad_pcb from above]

Board: 2 copper layers, 56.5 x 40.5 mm, 30 parts (0 on the bottom side), 10 nets.

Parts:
C1: 10uF/25V; C_1210_3225Metric
C2, C3, C8, C9: 100nF; C_0402_1005Metric
C4, C5: 22uF; C_0805_2012Metric
C6: 100uF; C_1206_3216Metric
C7: 10uF; C_0603_1608Metric
D1: SMF5.0A; D_SOD-123F
FID1, FID2, FID3: Fiducial; Fiducial_1mm_Mask2mm
H1, H2, H3, H4: M3; MountingHole_3.2mm_M3_Pad_Via
H5: M2 standoff H2.5; SMTSO_M2_H2.5_SMTSOM225BTR
J1: USB-C; USB_C_Receptacle_HRO_TYPE-C-31-M-12
J2: M.2 Key-E (GW16170); CONN-SMD_MLD-NGFF-E-4.2H
L1: 2.2uH; IND-SMD_L7.2-W6.6_GPSR07X0
R1, R2: 5.1k; R_0402_1005Metric
R3: 33.2k; R_0402_1005Metric
R4: 10k; R_0402_1005Metric
TP1: +3V3; TestPoint_Pad_D1.5mm
TP2: VBUS; TestPoint_Pad_D1.5mm
TP3: GND; TestPoint_Pad_D1.5mm
U1: USBLC6-2SC6; SOT-23-6
U2: TPS563201DDCR; SOT-23-6

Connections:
+3V3: C4.1, C5.1, C6.1, C7.1, C8.1, C9.1, J2.2, J2.4, J2.72, J2.74, L1.2, R3.1, TP1.1
/CC1: J1.A5, R1.1
/CC2: J1.B5, R2.1
/FB: R3.2, R4.1, U2.4
/SW: C3.1, L1.1, U2.2
/USB_D_N: J1.A7, J1.B7, J2.5, U1.1, U1.6
/USB_D_P: J1.A6, J1.B6, J2.3, U1.3, U1.4
/VBST: C3.2, U2.6
GND: C1.2, C2.2, C4.2, C5.2, C6.2, C7.2, C8.2, C9.2, D1.2, H1.1, H2.1, H3.1, H4.1, H5.1, J1.A1, J1.A12, J1.B1, J1.B12, J1.SH, J2.1, J2.7, J2.18, J2.33, J2.39, J2.45, J2.51, J2.57, J2.63, J2.69, J2.75, J2.76, J2.77, R1.2, R2.2, R4.2, TP3.1, U1.2, U2.1
VBUS: C1.1, C2.1, D1.1, J1.A4, J1.A9, J1.B4, J1.B9, TP2.1, U2.3, U2.5

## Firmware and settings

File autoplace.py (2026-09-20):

#!/usr/bin/env python3
"""Netlist-driven PCB placement: recipes -> blocks -> floor plan -> board.

    python autoplace.py PROJECT_DIR --selftest       # prove the geometry model on this board
    python autoplace.py PROJECT_DIR --audit          # score the board's current placement
    python autoplace.py PROJECT_DIR --floorplan      # propose; writes floorplan.svg/.json, board untouched
    python autoplace.py PROJECT_DIR --place          # place, link, check, save, DRC, render

Run with KiCad's Python. PROJECT_DIR must hold placement_config.py (see
references/autoplace.md for every key). Locked footprints (KiCad's lock flag)
and parts in FIXED never move; everything else is re-placed on every run.

How it works
  1. Model: every footprint's pads and courtyard in its own unrotated frame,
     read from the board itself; --selftest proves the rotate/flip maths
     against the real pad positions before anything is trusted.
  2. Blocks: each IC/connector is matched to a recipe (scripts/recipes.py) by
     pin names. Roles claim support parts through the netlist -- "the cap
     between VIN and GND" -- in priority order across the whole board.
     Leftover passives join the block they share the most local net with.
  3. Block solve: inside each block the anchor sits at the origin and members
     are placed one by one, closest-first in priority order, at the position
     that minimises pad-to-pin distance without overlapping.
  4. Board solve: fixed parts and keep-outs go in first. Blocks are then
     placed as rigid units, most-connected first, at the position/rotation/
     side with the lowest weighted wirelength to what is already placed,
     then improved by re-placing each block against all the others.
  5. Audit: every role is measured on the result against its recipe limit.
"""
import argparse
import importlib.util
import json
import math
import os
import re
import sys
import time

HERE = os.path.dirname(os.path.abspath(__file__))
sys.path.insert(0, HERE)
import pcbnew  # noqa: E402
from pcblib import Board, say  # noqa: E402
import recipes as R  # noqa: E402

PASSIVE = {"C", "R", "L", "D", "FB", "Y"}


# ===========================================================================
# geometry
# ===========================================================================
class Pad:
    __slots__ = ("num", "cx", "cy", "x0", "y0", "x1", "y1", "th")

    def __init__(self, num, cx, cy, x0, y0, x1, y1, th):
        self.num, self.cx, self.cy = num, cx, cy
        self.x0, self.y0, self.x1, self.y1, self.th = x0, y0, x1, y1, th


# Conventions, confirmed by selftest() against real pad positions:
# a bottom-side footprint is mirrored in X about its origin, then rotated by
# its orientation; KiCad's positive rotation turns +X toward -Y (Y is down).
BOTTOM_MIRROR = "y"      # proven on pcbnew 10.0.6 with FLIP_DIRECTION_LEFT_RIGHT
ROT_SIGN = 1


def xform(lx, ly, x, y, rot, bottom):
    if bottom:
        if BOTTOM_MIRROR == "x":
            lx = -lx
        else:
            ly = -ly
    a = math.radians(rot) * ROT_SIGN
    c, s = math.cos(a), math.sin(a)
    return x + lx * c + ly * s, y - lx * s + ly * c


def xrect(r, x, y, rot, bottom):
    pts = [xform(px, py, x, y, rot, bottom) for px, py in
           ((r[0], r[1]), (r[2], r[1]), (r[0], r[3]), (r[2], r[3]))]
    xs = [p[0] for p in pts]
    ys = [p[1] for p in pts]
    return (min(xs), min(ys), max(xs), max(ys))


def overlap(a, b, gap=0.0):
    return not (a[2] + gap <= b[0] or b[2] + gap <= a[0] or a[3] + gap <= b[1] or b[3] + gap <= a[1])


def grow(r, d):
    return (r[0] - d, r[1] - d, r[2] + d, r[3] + d)


def union(rs):
    return (min(r[0] for r in rs), min(r[1] for r in rs), max(r[2] for r in rs), max(r[3] for r in rs))


def parse_cap(v):
    m = re.match(r"\s*([\d.]+)\s*([pnuµm]?)F?", v or "", re.I)
    if not m:
        return None
    mult = {"p": 1e-12, "n": 1e-9, "u": 1e-6, "µ": 1e-6, "m": 1e-3, "": 1.0}[m.group(2).lower()]
    try:
        return float(m.group(1)) * mult
    except ValueError:
        return None


def kind_of(ref):
    m = re.match(r"[A-Za-z]+", ref)
    p = m.group(0).upper() if m else "?"
    for k in ("SW", "FB", "TP"):
        if p.startswith(k):
            return k
    return p[0]


# ===========================================================================
# model
# ===========================================================================
# Seated height in mm, by package, as a *maximum* over the common parts in
# that package -- a zone under a card is only safe if every part that may end
# up there fits, not the typical one. Where a footprint or its 3D model names
# its own height (easyeda2kicad writes "...-H0.6-..."), that number wins.
PACKAGE_HEIGHT = {
    "0201": 0.35, "0402": 0.55, "0603": 0.95, "0805": 1.25, "1206": 1.60,
    "1210": 2.00, "1812": 2.00, "2010": 2.00, "2512": 2.00,
    "SOD-523": 0.60, "SOD-323": 1.10, "SOD-123": 1.35, "SOT-23": 1.45,
    "SOT-25": 1.45, "SOT-26": 1.45, "SOT-323": 1.10, "SOT-353": 1.10,
    "SOT-363": 1.10, "USON": 0.60, "DFN": 0.80, "QFN": 1.00, "SOIC": 1.75,
    "SSOP": 2.00, "TSSOP": 1.20, "VSON": 0.80,
}
_H_IN_NAME = re.compile(r"[-_]H(\d+(?:\.\d+)?)")


def part_height(p):
    """Seated height in mm, or None when nothing says.

    None is not zero: a part whose height is unknown is refused by a
    height-limited zone rather than assumed to fit."""
    for name in (getattr(p, "model", "") or "", getattr(p, "footprint", "") or ""):
        m = _H_IN_NAME.search(name)
        if m:
            return float(m.group(1))
    fp = (getattr(p, "footprint", "") or "").upper()
    for key, h in sorted(PACKAGE_HEIGHT.items(), key=lambda kv: -len(kv[0])):
        if key in fp:
            return h
    return None


class Part:
    def __init__(self, ref):
        self.ref, self.kind = ref, kind_of(ref)
        self.value, self.pads, self.pin_names, self.nets = "", {}, {}, {}
        self.rect = (0, 0, 0, 0)
        self.x = self.y = self.rot = 0.0
        self.bottom = False
        self.locked = False
        self.cap = None
        self.has_courtyard = False
        self.footprint = ""
        self.model = ""

    @property
    def two_pin(self):
        return len({n for n in self.nets.values() if n}) <= 3 and self.kind in PASSIVE

    def netset(self):
        return {n for n in self.nets.values() if n}

    def pads_on(self, net):
        return [p for num, p in self.pads.items() if self.nets.get(num) == net]


class Model:
    def __init__(self, board):
        self.b = board
        root = board._netlist_root()
        libparts = {(lp.get("lib"), lp.get("part")): lp for lp in root.iter("libpart")}
        comps = {c.get("ref"): c for c in root.iter("comp")}
        self.nets = {}
        for n in root.iter("net"):
            self.nets[n.get("name")] = [(x.get("ref"), x.get("pin")) for x in n.findall("node")]
        self.parts = {}
        for ref, fp in board.fps.items():
            if ref not in comps:
                continue
            p = Part(ref)
            c = comps[ref]
            p.value = c.findtext("value") or ""
            p.footprint = c.findtext("footprint") or ""
            try:
                models = [m.GetFileName() for m in fp.Models()]
                p.model = models[0] if models else ""
            except Exception:
                p.model = ""
            sp = c.find("sheetpath")
            p.sheet = sp.get("names") if sp is not None else "/"
            ls = c.find("libsource")
            lp = libparts.get((ls.get("lib"), ls.get("part"))) if ls is not None else None
            if lp is not None:
                p.pin_names = {pin.get("num"): pin.get("name") or "" for pin in lp.iter("pin")}
            self._read_geometry(fp, p)
            p.cap = parse_cap(p.value) if p.kind == "C" else None
            self.parts[ref] = p
        for name, nodes in self.nets.items():
            for ref, pin in nodes:
                if ref in self.parts:
                    self.parts[ref].nets[pin] = name
        self.ground = {n for n, nodes in self.nets.items() if self._is_ground(n, nodes)}

    def _is_ground(self, name, nodes):
        if R.GROUND_RE.search(name):
            return True
        names = [self.parts[r].pin_names.get(p, "") for r, p in nodes if r in self.parts]
        return bool(names) and all(re.match(r"^(A|D|P)?GND|^VSS", n or "", re.I) for n in names)

    def _read_geometry(self, fp, p):
        mm = pcbnew.ToMM
        p.locked = fp.IsLocked()
        pos = fp.GetPosition()
        p.bottom = fp.IsFlipped()
        p.rot = fp.GetOrientationDegrees() % 360
        p.x, p.y = self.b.rel(pos)
        # normalise to the unrotated, unflipped frame, read, then restore
        if p.bottom:
            fp.Flip(pos, pcbnew.FLIP_DIRECTION_LEFT_RIGHT)
        fp.SetOrientationDegrees(0)
        fp.SetPosition(pcbnew.VECTOR2I(0, 0))
        rects = []
        p.padlist = []
        for pad in fp.Pads():
            bb = pad.GetBoundingBox()
            c = pad.GetPosition()
            th = pad.GetAttribute() in (pcbnew.PAD_ATTRIB_PTH, pcbnew.PAD_ATTRIB_NPTH)
            pd = Pad(pad.GetNumber(), mm(c.x), mm(c.y), mm(bb.GetX()), mm(bb.GetY()),
                     mm(bb.GetRight()), mm(bb.GetBottom()), th)
            p.padlist.append(pd)
            if pad.GetNumber() and pad.GetNumber() not in p.pads:
                p.pads[pad.GetNumber()] = pd
            elif not pad.GetNumber():
                p.pads["_np%d" % len(p.pads)] = pd
            rects.append((pd.x0, pd.y0, pd.x1, pd.y1))
        cy = fp.GetCourtyard(pcbnew.F_CrtYd)
        if cy.OutlineCount():
            bb = cy.BBox()
            rects.append((mm(bb.GetX()), mm(bb.GetY()), mm(bb.GetRight()), mm(bb.GetBottom())))
            p.has_courtyard = True
        p.rect = union(rects) if rects else (-0.5, -0.5, 0.5, 0.5)
        if p.bottom:
            fp.Flip(fp.GetPosition(), pcbnew.FLIP_DIRECTION_LEFT_RIGHT)
        fp.SetPosition(pos)
        fp.SetOrientationDegrees(p.rot)

    def pin_nets(self, part, pattern):
        """nets of the anchor pins whose names match a role pin regex"""
        rx = re.compile(pattern, re.I)
        out = {}
        for num, name in part.pin_names.items():
            if rx.search(name or "") and part.nets.get(num):
                out.setdefault(part.nets[num], []).append(num)
        # symbols whose pins are just numbers (connectors): match on the number
        if not out:
            for num, net in part.nets.items():
                if net and rx.search(num):
                    out.setdefault(net, []).append(num)
        return out


def selftest(board, model):
    """Prove xform() reproduces KiCad's own pad positions for every footprint."""
    global BOTTOM_MIRROR, ROT_SIGN
    actual = {}
    for ref, fp in board.fps.items():
        actual[ref] = [board.rel(pd.GetPosition()) for pd in fp.Pads()]
    results, per_part = {}, {}
    # "y" first: with no bottom-side parts both mirrors score 0, and the tie
    # must fall to the convention already proven on a double-sided board
    for mirror in ("y", "x"):
        for sign in (1, -1):
            BOTTOM_MIRROR, ROT_SIGN = mirror, sign
            worst, parts_err = 0.0, {}
            for ref, p in model.parts.items():
                act = actual.get(ref, [])
                for i, pad in enumerate(p.padlist):
                    if i >= len(act):
                        break
                    ex, ey = xform(pad.cx, pad.cy, p.x, p.y, p.rot, p.bottom)
                    e = math.hypot(ex - act[i][0], ey - act[i][1])
                    parts_err[ref] = max(parts_err.get(ref, 0.0), e)
                    worst = max(worst, e)
            results[(mirror, sign)] = worst
            per_part[(mirror, sign)] = parts_err
    best = min(results, key=results.get)
    BOTTOM_MIRROR, ROT_SIGN = best
    if results[best] > 0.01:
        errs = sorted(per_part[best].items(), key=lambda t: -t[1])[:8]
        for ref, e in errs:
            p = model.parts[ref]
            say("   %-6s err %.3f mm  rot %.1f %s" % (ref, e, p.rot, "bottom" if p.bottom else "top"))
        for k, v in results.items():
            say("   convention %s: worst %.3f" % (k, v))
    n_bot = sum(1 for p in model.parts.values() if p.bottom)
    say("selftest: bottom mirror=%s rotation sign=%+d, worst pad error %.4f mm over %d parts (%d on bottom)"
        % (best[0], best[1], results[best], len(model.parts), n_bot))
    if results[best] > 0.01:
        raise SystemExit("selftest FAILED: geometry model does not match KiCad (%.3f mm)" % results[best])
    if n_bot == 0:
        say("  note: no bottom-side parts on this board, so the flip convention is unproven")
    return results[best]


# ===========================================================================
# blocks
# ===========================================================================
class Member:
    def __init__(self, part, role, recipe, targets):
        self.part, self.role, self.recipe, self.targets = part, role, recipe, targets
        self.lx = self.ly = self.lrot = 0.0


class Block:
    def __init__(self, anchor, recipe):
        self.anchor, self.recipe = anchor, recipe
        self.members = []          # Member, anchor excluded
        self.name = anchor.ref
        self.rects = []            # (ref, rect in block frame)
        self.tags = set(recipe.tags) if recipe else set()

    def refs(self):
        return [self.anchor.ref] + [m.part.ref for m in self.members]


def _ref_hint(anchor_ref, part_ref):
    a = re.sub(r"^[A-Z]+", "", anchor_ref.upper())
    body = re.sub(r"^[A-Z]", "", part_ref.upper())
    full = anchor_ref.upper()
    best = 0
    for s in (full, a):
        for i in range(len(s)):
            for j in range(i + 2, len(s) + 1):
                if s[i:j] in body and (j - i) > best:
                    best = j - i
    return best


def build_blocks(model, cfg):
    parts = model.parts
    recipes = list(getattr(cfg, "EXTRA_RECIPES", [])) + R.RECIPES
    anchors = sorted((p for p in parts.values() if p.kind not in PASSIVE or p.kind == "Y" and False),
                     key=lambda p: (-len(p.pads), p.ref))
    anchors = [p for p in anchors if p.kind in {"U", "Q", "J", "T", "SW", "Y"} or p.kind not in PASSIVE]
    recipe_of = {}
    for p in anchors:
        for rc in recipes:
            if rc.matches(p):
                recipe_of[p.ref] = rc
                break
    for p in anchors:
        if p.ref not in recipe_of:
            for rc in R.FALLBACKS:
                if rc.matches(p):
                    recipe_of[p.ref] = rc
                    break

    owner = {}                          # part ref -> (anchor ref, role name)
    assigned = {a.ref: {} for a in anchors}   # anchor -> role -> [refs]
    claimed_anchor = set()

    def role_targets(anchor, role, part):
        """(net, [(target kind, ref, pad nums)], weight) for this candidate, or None"""
        a_nets = _side_nets(anchor, role.a, assigned[anchor.ref])
        if a_nets is None:
            return None
        pn = part.netset()
        hit_a = [n for n in a_nets if n in pn and n not in model.ground]
        if role.a == "GND":
            hit_a = [n for n in pn if n in model.ground]
        if not hit_a:
            return None
        rest = pn - set(hit_a)
        if role.b == "*":
            hit_b = []
        elif role.b == "GND":
            hit_b = [n for n in rest if n in model.ground]
            if not hit_b:
                return None
        else:
            b_nets = _side_nets(anchor, role.b, assigned[anchor.ref])
            if b_nets is None:
                return None
            hit_b = [n for n in rest if n in b_nets]
            if not hit_b:
                return None
        return hit_a, hit_b

    def _side_nets(anchor, spec, roles_done):
        if spec in ("*", "GND"):
            return set()
        if spec.startswith("role:"):
            rname = spec[5:]
            refs = roles_done.get(rname)
            if not refs:
                return None
            nets = set()
            for r in refs:
                nets |= parts[r].netset()
            # the other side of that role's part: every net it has except the anchor's own
            return {n for n in nets if n not in anchor.netset() and n not in model.ground}
        return set(model.pin_nets(anchor, spec))

    def eligible(part, role, anchor):
        if part.ref == anchor.ref or part.ref in owner or part.ref in claimed_anchor:
            return False
        if part.locked and False:
            return False
        if role.kind == "*":
            if part.kind not in PASSIVE:
                return False
        elif part.kind != role.kind:
            return False
        if part.kind in PASSIVE and len(part.pads) > 8:
            return False
        if part.kind not in PASSIVE and role.kind != part.kind:
            return False
        return True

    # nets each schematic sheet's anchors have pins on: a rail capacitor drawn
    # on a sheet belongs to an IC on that sheet if one uses the rail
    sheet_nets = {}
    for a in anchors:
        sheet_nets.setdefault(getattr(a, "sheet", "/"), set()).update(a.netset())

    def run_pass(recipe_filter, min_hint=0):
        prios = sorted({r.prio for a in anchors if a.ref in recipe_of for r in recipe_of[a.ref].roles})
        for prio in prios:
            cands = []
            for a in anchors:
                if a.ref in claimed_anchor:
                    continue
                rc = recipe_of.get(a.ref)
                if rc is None or not recipe_filter(rc):
                    continue
                for role in rc.roles:
                    if role.prio != prio:
                        continue
                    for part in parts.values():
                        if not eligible(part, role, a):
                            continue
                        hit = role_targets(a, role, part)
                        if not hit:
                            continue
                        hit_a, hit_b = hit
                        if rc in R.FALLBACKS:
                            # generic roles only take parts on local nets, or
                            # decoupling on a net this IC actually has a pin on
                            big = [n for n in hit_a if len(model.nets[n]) > 6]
                            if role.name == "local_passive" and big:
                                continue
                        hint = _ref_hint(a.ref, part.ref)
                        if hint < min_hint:
                            continue
                        big = [n for n in hit_a + hit_b if n not in model.ground and len(model.nets[n]) > 6]
                        psheet, asheet = getattr(part, "sheet", "/"), getattr(a, "sheet", "/")
                        if big and psheet != asheet and hint < 2 and \
                                any(n in sheet_nets.get(psheet, ()) for n in big):
                            continue
                        cap = part.cap or 0
                        pref = (-cap if role.prefer == "large" else cap) if role.prefer else 0
                        local = min(len(model.nets[n]) for n in hit_a)
                        cands.append(((-hint, pref, local, part.ref), a, role, part, hit_a, hit_b))
            cands.sort(key=lambda c: c[0])
            for _k, a, role, part, hit_a, hit_b in cands:
                if part.ref in owner or a.ref in claimed_anchor:
                    continue
                taken = assigned[a.ref].setdefault(role.name, [])
                limit = role.count
                if limit == 0 and role.b == "GND":
                    # "all" decoupling means one cap per anchor pin on that net
                    limit = sum(len(model.pin_nets(a, role.a).get(n, [])) for n in hit_a) or 1
                    same = [r for r in taken if set(hit_a) & parts[r].netset()]
                    if len(same) >= limit:
                        continue
                elif limit and len(taken) >= limit:
                    continue
                owner[part.ref] = (a.ref, role.name, hit_a, hit_b)
                taken.append(part.ref)
                if part.kind not in PASSIVE:
                    claimed_anchor.add(part.ref)

    def rc_is_generic(rc, role):
        return rc in R.FALLBACKS and role.name.startswith("c_decouple")

    run_pass(lambda rc: rc not in R.FALLBACKS, min_hint=2)   # designator affinity first (CU33O1 -> U331)
    run_pass(lambda rc: rc not in R.FALLBACKS)
    run_pass(lambda rc: rc in R.FALLBACKS)

    # leftovers: passives nobody claimed join the block they share the most
    # local net with
    leftovers = [p for p in parts.values() if p.kind in PASSIVE and p.ref not in owner]
    anchor_refs = [a.ref for a in anchors if a.ref not in claimed_anchor]
    for p in sorted(leftovers, key=lambda q: q.ref):
        best = None
        for net in p.netset():
            if net in model.ground:
                continue
            size = len(model.nets[net])
            for ref, _pin in model.nets[net]:
                home = ref if ref in anchor_refs else (owner[ref][0] if ref in owner else None)
                if home is None or home == p.ref:
                    continue
                pin_name = parts[ref].pin_names.get(_pin, "") if ref == home else ""
                source = 0 if re.search(r"^(SYS|OUT|VOUT|VBUS)$", pin_name or "", re.I) else 1
                other_sheet = getattr(parts[home], "sheet", "/") != getattr(p, "sheet", "/")
                key = (other_sheet, size, source, home)
                if best is None or key < best[0]:
                    best = (key, home, net)
        if best:
            owner[p.ref] = (best[1], "attached", [best[2]], [])
            assigned[best[1]].setdefault("attached", []).append(p.ref)
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

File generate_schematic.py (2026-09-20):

#!/usr/bin/env python3
"""USB-C (USB 2.0) to M.2 Key-E carrier for the Gateworks GW16170 HaLow card.

The .kicad_sch is GENERATED -- edit this script, then run it with KiCad's Python:

    "C:\\Program Files\\KiCad\\10.0\\bin\\python.exe" generate_schematic.py [--force]

Spec first (PARTS / NETS / NO_CONNECT), drawing second, then KiCad's own
netlist proves the drawing matches the spec.
"""
import argparse
import os
import sys

HERE = os.path.dirname(os.path.abspath(__file__))
sys.path.insert(0, HERE)
from schlib import Design, snap                     # noqa: E402
from subcircuits import Refs, Spec, UsbCSink, passive  # noqa: E402

NAME = "USBC_M2E_HaLow_Adapter"
LIB = "HaLowAdapter"

# ---------------------------------------------------------------------------
# Spec
# ---------------------------------------------------------------------------
refs, spec = Refs(), Spec()
# U1 pin 5 (VBUS) is left open: it sits between D+ and D- in a flow-through layout,
# so on two layers the only way to reach it is a bottom trace that slots the ground
# plane under the data lines. The array clamps through its internal TVS either way;
# VBUS has its own clamp, D1.
usb = spec.add(UsbCSink(refs, vbus="VBUS", dp="USB_D_P", dm="USB_D_N", esd_vbus=False,
                        title="USB-C INPUT, ESD & VBUS CLAMP (J1/U1/D1)"))
J1, U1 = usb.j, usb.esd
# LCSC numbers below come from the owner's ordered CM4 OpenMANET BOM
p = usb.parts
# project copy of the stock footprint: it carries the vendor 3D model
p[J1] = p[J1][:2] + (f"{LIB}:USB_C_Receptacle_HRO_TYPE-C-31-M-12", "C165948", "HRO", "TYPE-C-31-M-12")
p[U1] = p[U1][:3] + ("C7519", "STMicroelectronics", "USBLC6-2SC6")
spec.PARTS.update(p)


def add(ref, tup):
    refs.reserve(ref)
    spec.PARTS[ref] = tup
    return ref


D1 = add("D1", ("Device:D_Zener", "SMF5.0A", "Diode_SMD:D_SOD-123F", "C19077497", "R+O", "SMF5.0A"))
U2 = add("U2", ("Regulator_Switching:TPS563201", "TPS563201DDCR", "Package_TO_SOT_SMD:SOT-23-6",
                "C116592", "Texas Instruments", "TPS563201DDCR"))
# 2.2 uH, not 4.7: TI Table 2 gives 2.2 uH typical for 3.3 V and 20-68 uF of output
# capacitance. This rail carries ~87 uF effective (154 uF nominal) with the socket's bulk
# cap, and 2.2 uH keeps the LC double pole (8.6-11.5 kHz) inside TI's envelope.
L1 = add("L1", ("Device:L", "2.2uH", f"{LIB}:IND-SMD_L7.2-W6.6_GPSR07X0", "C5189746", "SHOU HAN",
                "CYA0630-2.2UH"))
C1 = add("C1", ("Device:C", "10uF/25V", "Capacitor_SMD:C_1210_3225Metric", "C77100", "Murata",
                "GRM32DR71E106KA12L"))
C2 = add("C2", passive("C", "100nF"))
C3 = add("C3", passive("C", "100nF"))
C4 = add("C4", passive("C", "22uF"))
C5 = add("C5", passive("C", "22uF"))
R3 = add("R3", ("Device:R", "33.2k", "Resistor_SMD:R_0402_1005Metric", "C2930001", "Uniroyal",
                "FRC0402F3322TS"))
R4 = add("R4", passive("R", "10k"))
J2 = add("J2", (f"{LIB}:M2_Socket_E_MLD-NGFF-E-4.2H", "M.2 Key-E (GW16170)",
                f"{LIB}:CONN-SMD_MLD-NGFF-E-4.2H", "C52766479", "MLD", "MLD-NGFF-E-4.2H"))
C6 = add("C6", ("Device:C", "100uF", "Capacitor_SMD:C_1206_3216Metric", "C15008", "Samsung",
                "CL31A107MQHNNNE"))
C7 = add("C7", passive("C", "10uF"))
C8 = add("C8", passive("C", "100nF"))
C9 = add("C9", passive("C", "100nF"))
M3 = ("Mechanical:MountingHole_Pad", "M3", "MountingHole:MountingHole_3.2mm_M3_Pad_Via", "", "", "")
HOLES = [add(f"H{i}", M3) for i in range(1, 5)]
# 2.5 mm: the MLD drawing puts the card centre 2.92 mm above the board and the
# card is 0.8 mm thick, so its underside sits at 2.52 mm
H5 = add("H5", ("Mechanical:MountingHole_Pad", "M2 standoff H2.5",
                f"{LIB}:SMTSO_M2_H2.5_SMTSOM225BTR", "C5301773", "YIYUAN", "SMTSOM225BTR"))
FIDS = [add(f"FID{i}", ("Mechanical:Fiducial", "Fiducial", "Fiducial:Fiducial_1mm_Mask2mm", "", "", ""))
        for i in range(1, 4)]
TPS = {add(f"TP{i}", ("Connector:TestPoint", net, "TestPoint:TestPoint_Pad_D1.5mm", "", "", "")): net
       for i, net in enumerate(("+3V3", "VBUS", "GND"), 1)}

M2_GND = ["1", "7", "18", "33", "39", "45", "51", "57", "63", "69", "75"]
M2_3V3 = ["2", "4", "72", "74"]
M2_USED = set(M2_GND + M2_3V3 + ["3", "5", "76", "77"])
M2_ALL = [str(n) for n in range(1, 78) if not 24 <= n <= 31]

N = spec.NETS
N["VBUS"] += [(D1, "1"), (U2, "3"), (U2, "5"), (C1, "1"), (C2, "1")]
N["GND"] += ([(D1, "2"), (U2, "1"), (C1, "2"), (C2, "2"), (C4, "2"), (C5, "2"), (R4, "2"),
              (C6, "2"), (C7, "2"), (C8, "2"), (C9, "2"), (J2, "76"), (J2, "77"), (H5, "1")]
             + [(J2, n) for n in M2_GND] + [(h, "1") for h in HOLES])
N["+3V3"] += ([(L1, "2"), (R3, "1"), (C4, "1"), (C5, "1"), (C6, "1"), (C7, "1"), (C8, "1"),
               (C9, "1")] + [(J2, n) for n in M2_3V3])
for _tp, _net in TPS.items():
    N[_net] += [(_tp, "1")]
N["SW"] += [(U2, "2"), (L1, "1"), (C3, "1")]
N["VBST"] += [(U2, "6"), (C3, "2")]
N["FB"] += [(U2, "4"), (R3, "2"), (R4, "1")]
N["USB_D_P"] += [(J2, "3")]
N["USB_D_N"] += [(J2, "5")]
spec.NO_CONNECT += [(J2, n) for n in M2_ALL if n not in M2_USED]
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

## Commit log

2026-09-20 USB-C to M.2 Key-E HaLow adapter, Rev A as sent to JLCPCB
    USB 2.0 over USB-C to an M.2 2230 Key-E socket for the Gateworks GW16170
    HaLow card. 56.5 x 40.5 mm, 2 layers, TPS563201 3.3 V buck.
    Includes the KiCad 10 project, the Python generators for the schematic,
    placement, fab rules, routing and the JLCPCB package, the fabrication
    package itself, and the pre-fab design review.
    [USBC_M2E_HaLow_Adapter-B_Cu.gbl, USBC_M2E_HaLow_Adapter-B_Mask.gbs, USBC_M2E_HaLow_Adapter-B_Paste.gbp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]
2026-09-20 Add CERN-OHL-P-2.0 and MIT licences, top-level BOM, public README
    Hardware under CERN-OHL-P v2, Python generators under MIT. Third-party
    footprints and 3D models are listed as not covered. BOM.md gives the full
    bill of materials with LCSC numbers and the parts a builder supplies.
2026-09-30 Rev A works as designed: close out
    Boards assembled by JLCPCB confirmed working on 2026-09-29. README status
    updated, board test procedure added, and the placement-file corrections
    marked verified now that an assembled order has proven them.
